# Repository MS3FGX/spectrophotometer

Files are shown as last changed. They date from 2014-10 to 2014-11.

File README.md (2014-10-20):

Simple Spectrophotometer
==============

From [Wikipedia](http://en.wikipedia.org/wiki/Spectrophotometry):

*A spectrophotometer is commonly used for the measurement of transmittance or
reflectance of solutions, transparent or opaque solids, such as polished glass,
or gases.*

This is a very simple fixed wavelength spectrophotometer for 1.5 and 2.0 ml
centrifuge tubes that I've designed to aid quantifying algae growth from
different experimental cultures by way of
[fluid turbidity](http://en.wikipedia.org/wiki/Turbidity).

The STL files for its physical components, as well as the Arduino firmware, are
released in the hope that others might find this device useful.

Principle of Operation
==============

Two white LEDs are positioned exactly opposite each other on either side of
the sample tube, one acting as a reference light source, and the other acting
as a ["Mimms Effect"](http://en.wikipedia.org/wiki/Forrest_Mims#Using_LEDs_as_narrow_band_light_sensors) photodiode.

The Arduino firmware reads the value off of the light sensor and compares that
to calibrated values for pure water to determine the sample's opacity compared
to pure water.

Further Work
==============

- Future improvements could include a tri-color LED to measure light
transmission at different wavelengths, bringing the device closer to a proper
spectrometer.

- More experiments are needed with different LEDs as the light sensor, other
colors are reported to work better.

Requirements 
==============

To compile this firmware, you'll need the following Arduino libraries:

#### Bounce2

http://github.com/thomasfredericks/Bounce-Arduino-Wiring/tree/master/Bounce2

#### LiquidCrystal_I2C

http://bitbucket.org/fmalpartida/new-liquidcrystal/wiki/Home

License
==============

The software is distributed under a BSD 3 clause license in the hope that it
will be useful, but WITHOUT ANY WARRANTY; without even the implied warranty of
MERCHANTABILITY or FITNESS FOR A PARTICULAR PURPOSE.

For details, see the file "LICENSE" in the source directory.

The physical objects are released under the Creative Commons BY-SA license.

For details, see: http://creativecommons.org/licenses/by-sa/3.0/

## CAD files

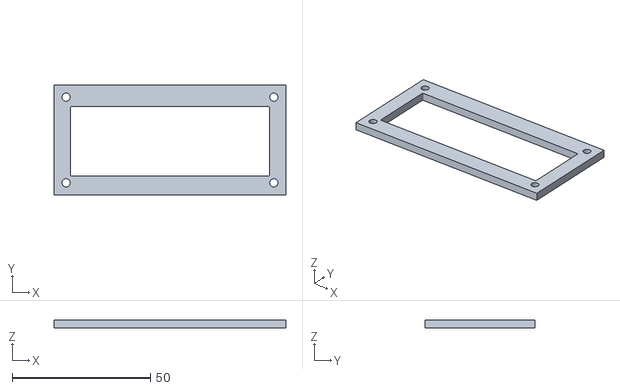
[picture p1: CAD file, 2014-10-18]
STL/lcd_bezel.stl
84.0 x 40.0 x 3.00

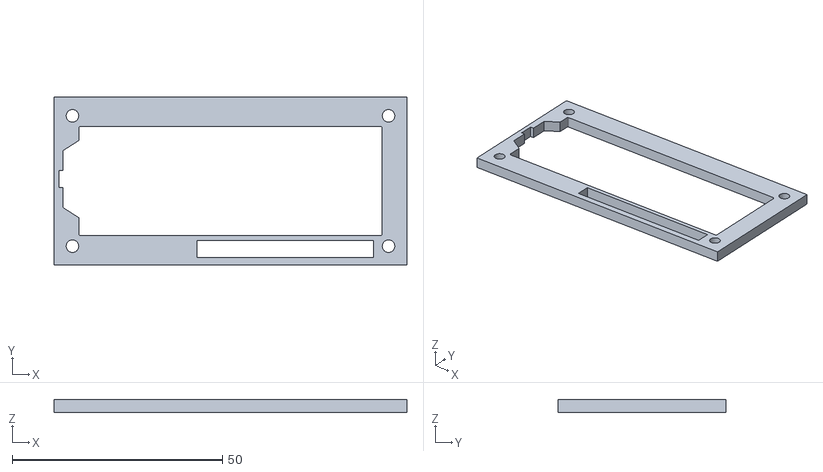
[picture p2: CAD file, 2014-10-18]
STL/lcd_spacer.stl
84.0 x 40.0 x 3.00

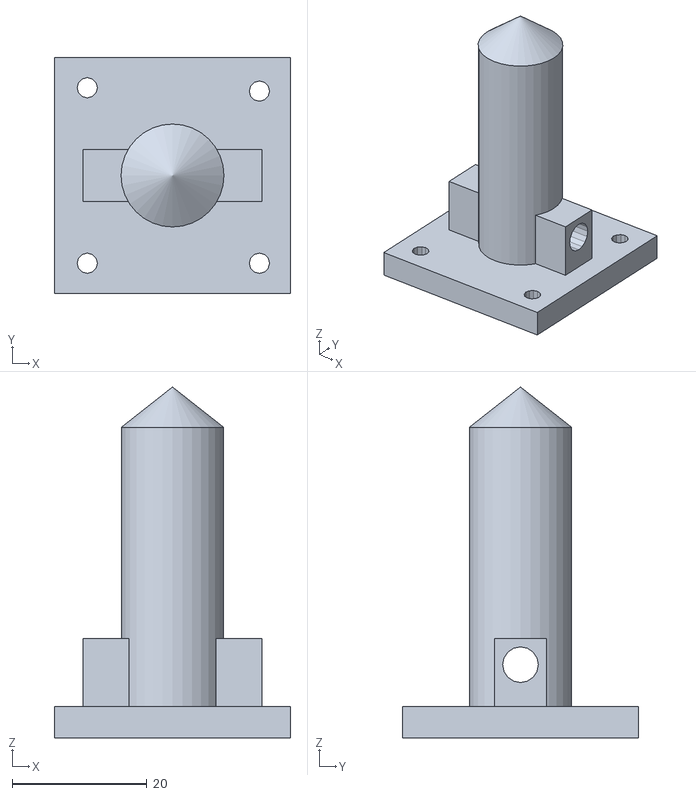
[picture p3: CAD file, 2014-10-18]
STL/sensor_chamber.stl
35.0 x 35.0 x 52.0

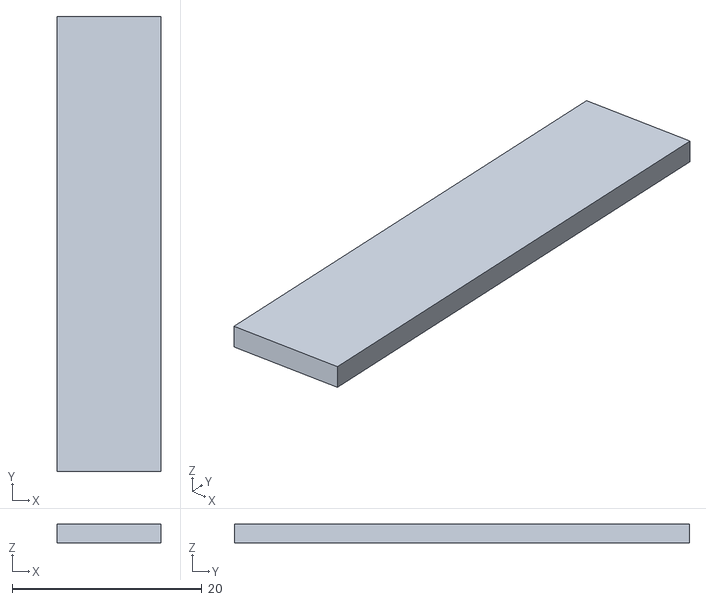
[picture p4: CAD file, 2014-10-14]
STL/pcb_spacer.stl
11.0 x 48.0 x 2.00

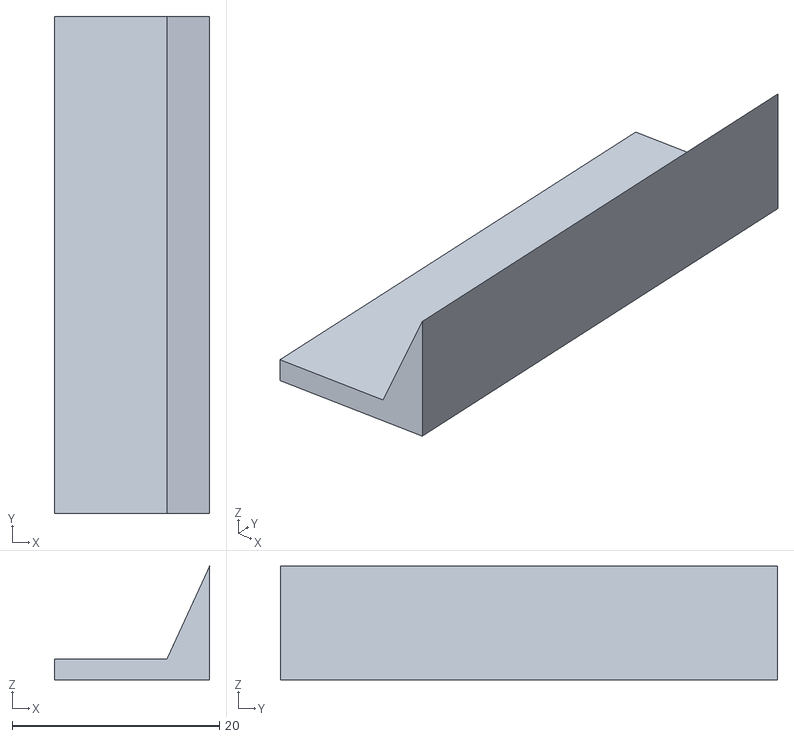
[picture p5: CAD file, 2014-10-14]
STL/battery_holder.stl
15.0 x 48.0 x 11.0

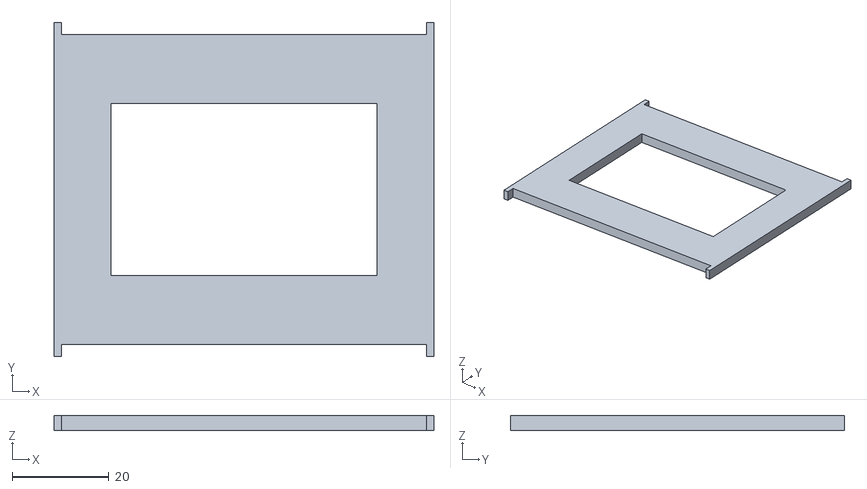
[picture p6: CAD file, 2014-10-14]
STL/pcb_tray.stl
78.5 x 69.0 x 3.00

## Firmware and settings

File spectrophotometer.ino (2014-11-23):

/*
  Firmware for 3D printed spectrophotometer.
  Developed by Tom Nardi (MS3FGX@gmail.com)
  Released under the BSD 3 Clause license
*/

// Version info
#define VERSION 1.2

// Libraries for hardware
#include <Wire.h>
#include <Bounce2.h>
#include <LiquidCrystal_I2C.h>

// I/O Lines
#define SENSOR A0
#define LED 3
#define BUTTON 2

// Set the LCD I2C address
LiquidCrystal_I2C lcd(0x27, 2, 1, 0, 4, 5, 6, 7, 3, POSITIVE);

// Calibration values for white ref LED
#define FULLBATT 5.15
#define NOSAMPLE 430
#define WATER 420
#define SENSE_DELAY 2000

// Sensor data
#define SAMPLES 100
int SensorArray [SAMPLES];

// Button object
Bounce SCAN_SMPL = Bounce ();

// Misc variables
int sensor_reading;
int debug = 0;

void setup()
{
  // Init serial coms
  Serial.begin(57600);
  Serial.println("Power on");
  
  // Setup LCD
  lcd.begin(20,4);
  
  // Print version and battery
  lcd.setCursor(0,0);
  lcd.print("V");
  lcd.print(VERSION);
  
  lcd.setCursor(8,0);
  lcd.print("Batt:");
  lcd.print(BatteryPercent());
  lcd.print("%");
  
  // Setup reference LED
  pinMode(LED, OUTPUT);
  
  // Setup button
  pinMode(BUTTON, INPUT);
  digitalWrite(BUTTON, HIGH);
  
  // If held, go to debug
  if (digitalRead(BUTTON) == LOW)
    debug = 1;
    
  // Setup bounce library
  SCAN_SMPL .attach(BUTTON);
  SCAN_SMPL .interval(10);

  // Exiting setup
  Serial.println("Ready");
}

void loop()
{  
  // Check for debug
  while (debug == 1)
  {
    // First line
    lcd.setCursor(0,0);
    lcd.print("DEBUG");
    lcd.setCursor(7,0);
    lcd.print("Volt:");
    lcd.print(readVcc()/1000.0);
    
    // LED on
    digitalWrite(LED, HIGH);
    lcd.setCursor(0,1);
    lcd.print("Sensor: ");
    lcd.print(ReadSensor());
    
    // Wait before loop
    delay(100);
  }
  
  // Let user know we are ready
  lcd.setCursor(0,1);
  lcd.print("Ready");
  
  // Scan for button
  SCAN_SMPL.update();
  
  if (SCAN_SMPL.fell())
  {    
    // Notification
    ClearLine(1);
    lcd.print("Analyzing...");
    Serial.println("Analyzing...");
    
    // Reference LED on
    digitalWrite(LED, HIGH);

    // Wait for sensor to stablize
    delay(SENSE_DELAY);
    
    // Read sensor and attempt to match
    sensor_reading = ReadSensor();
    if (sensor_reading >= NOSAMPLE)
    {
      ClearLine(1);
      lcd.print("No Sample!");
      Serial.println("No sample!");
    }
    else if (sensor_reading >= WATER)
    {
      ClearLine(1);
      lcd.print("Pure Water");
      Serial.println ("Water");
    }
    else
    {
      ClearLine(1);
      //lcd.print("Result: ");
      lcd.print(WaterPercent(sensor_reading));
      lcd.print("% water");
    }
    
    // Always print to serial for debug
    Serial.println(sensor_reading);
    
    // Reference LED off
    digitalWrite(LED, LOW);
  
    // Show results on screen for a bit
    delay(3000);
    
    // LCD clear
    ClearLine(1);
  }
}

// Return smoothed value from sensor
int ReadSensor()
{
  // Load data into array
  for (int x = 0; x < (SAMPLES - 1); x++)
  {
    SensorArray[x] = analogRead(A0);
    delay(20);
  }

  // Process data and return result
  int i, x, y, total;
  
  // Sort the array 
  for(i = 0; i < (SAMPLES - 1); i++)
  {
    for(x = 0; x < (SAMPLES - (i + 1)); x++)
    {
      if(SensorArray[x] > SensorArray[x+1])
      {
         int temp = SensorArray[x];
         SensorArray[x] = SensorArray[x + 1];
         SensorArray[x + 1] = temp;
       }
     }
  }
    
   // Remove top and bottom 20
   int TrimmedArray [SAMPLES - 20];
   y = 0;
   for(x = 19; x < (SAMPLES - 20); x++)
   {
     TrimmedArray[y] = SensorArray[x];
     y++;
   }
    
   // Average remaining values
   total = 0;
   for(x = 0; x < (y - 1); x++)
     total += TrimmedArray[x];
      
   return(total / (y - 1));  
}

long readVcc()
{
  long result;
  // Read 1.1V reference against AVcc
  ADMUX = _BV(REFS0) | _BV(MUX3) | _BV(MUX2) | _BV(MUX1);
  delay(2); // Wait for Vref to settle
  ADCSRA |= _BV(ADSC); // Convert
  while (bit_is_set(ADCSRA,ADSC));
  result = ADCL;
  result |= ADCH<<8;
  result = 1125300L / result; // Back-calculate AVcc in mV
  return result;
}

// Return percentage of battery against define calibration
int BatteryPercent()
{
  return(((readVcc()/1000.0) / FULLBATT) * 100);
}

// Return percentage of light transmission compared to water
int WaterPercent(double sensor)
{
  // Handle as double to keep precision
  return((sensor / WATER) * 100);
}

// Clear given line on LCD
void ClearLine(int line)
{
  // What a hack...
  lcd.setCursor(0,line);
  lcd.println("                ");
  lcd.setCursor(0,line);
}

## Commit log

2014-10-11 Final sensor chamber
    [sensor_chamber.stl, tube_chamber_sensor.stl]
2014-10-14 New parts, first commit
    [battery_holder.stl, pcb_spacer.stl, pcb_tray.stl]
2014-10-16 Removed, must redo
    [chamber_lid.stl]
2014-10-18 Changing mounting holes
    [sensor_chamber.stl]
2014-10-18 LCD mounting hardware
    [lcd_bezel.stl, lcd_spacer.stl]
